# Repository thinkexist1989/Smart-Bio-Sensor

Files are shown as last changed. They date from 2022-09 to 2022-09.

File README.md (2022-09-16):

# Smart-Bio-Sensor

石墨烯生物传感器

- Hardware：硬件，包括了采集板、运放板、跳线版
- Firmware：固件，基于STM32CubeMX，采用HAL库
- Windows：Windows下的数据实时显示
- Android：Android端的数据实时采集

## Citation

```bibtex
@article{hao2021intelligent,
  title={An Intelligent Graphene-Based Biosensing Device for Cytokine Storm Syndrome Biomarkers Detection in Human Biofluids},
  author={Hao, Zhuang and Luo, Yang and Huang, Cong and Wang, Ziran and Song, Guoli and Pan, Yunlu and Zhao, Xuezeng and Liu, Shaoqin},
  journal={Small},
  volume={17},
  number={29},
  pages={2101508},
  year={2021},
  publisher={Wiley Online Library}
}
```

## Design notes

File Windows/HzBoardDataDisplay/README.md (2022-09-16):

# HzBoardDataDisplay V1.2

本程序是为了配合Hz Data Collection Board V5.0使用的，可以在PC端配置串口，自动采集数据并实时显示。基于Qt 和 Chart Director实现。目前版本为V1.2。

实现的功能如下：

+ **串口配置** 自动检测串口，设置串口波特率、校验位、停止位、数据位
+ **一键启动** 点击RUN按钮，自动和串口建立通讯，发送数据采集指令并接受返回数据
+ **实时显示** 三路电压实时显示，并可以选择单独显示每一路电压
+ **改变输出电压** 点击SET按钮，可以改变输出电压大小，单位mV
+ **改变界面大小** 为了适应郝壮这个大SB的Mackbook Pro的高分屏，添加了用于界面缩放的按钮，可以成比例缩放界面大小。

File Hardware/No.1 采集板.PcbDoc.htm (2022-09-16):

Reporting Options

# File in Newer Format

Date | : | 2018/4/19
Time | : | 10:31:07
Filename | : | D:\BaiduCloud\PHD PROJECTS\For HZ\HZ_Project5\No.1 꽃섞겼.PcbDoc

Version | Warning
Release 14 | CAUTION - The Differential Pairs Routing rule added support for control of the width. Be aware that these widths must be manually entered as Width rules in this version.
Release 15 | CAUTION - Support of separate solder masks for top & bottom of pads added.
Release 15.1 | CAUTION - Support Multi-line PCB Text added.
Release 16.0 | CAUTION - Pad/Via hole size tolerance value added.

This file was generated by a later version of the software

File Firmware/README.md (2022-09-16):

# DataCollectionBoard_v2_Code

+ 这份代码是配合自己开发的供电与电压采集板使用的。
+ 采集板采用stm32f407vet6+ads1274+dac8830实现DA输出供电与AD电压采集。
+ 基于Keil编写

### 采集板功能
采集板是用来给石墨烯生物采集芯片供电并采集其电流的。
+ 采集板需要实现10mV 稳定供电输出
+ 石墨烯生物采集芯片输出电流在10uA~20uA之间，需要利用运放芯片实现电流电压转换与放大，输出电压在0.5V左右
+ 需要实现高精度电压采集
+ 需要实时接受上位机指令并返回所需信息
+ 显示屏实时显示电压信息

### 采集板功能
+ MCU采用STM32F103C8T6芯片
+ 电压输出采用TI公司16位高精度DA芯片DAC8830（单路输出）
+ 电压采集采用TI公司24位高精度AD芯片ADS1274（四路输入）
+ 电流电压转换采用LT公司高精度运放LT1462。
+ 和上位机通讯采用串口通讯，芯片采用FTDI的FT232RL USB转串口芯片
+ 显示屏采用0.96寸LED显示屏

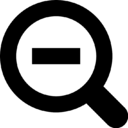
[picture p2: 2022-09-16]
Windows/HzBoardDataDisplay/zoomOut.png

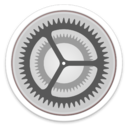
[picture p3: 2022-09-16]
Windows/HzBoardDataDisplay/Settings.png

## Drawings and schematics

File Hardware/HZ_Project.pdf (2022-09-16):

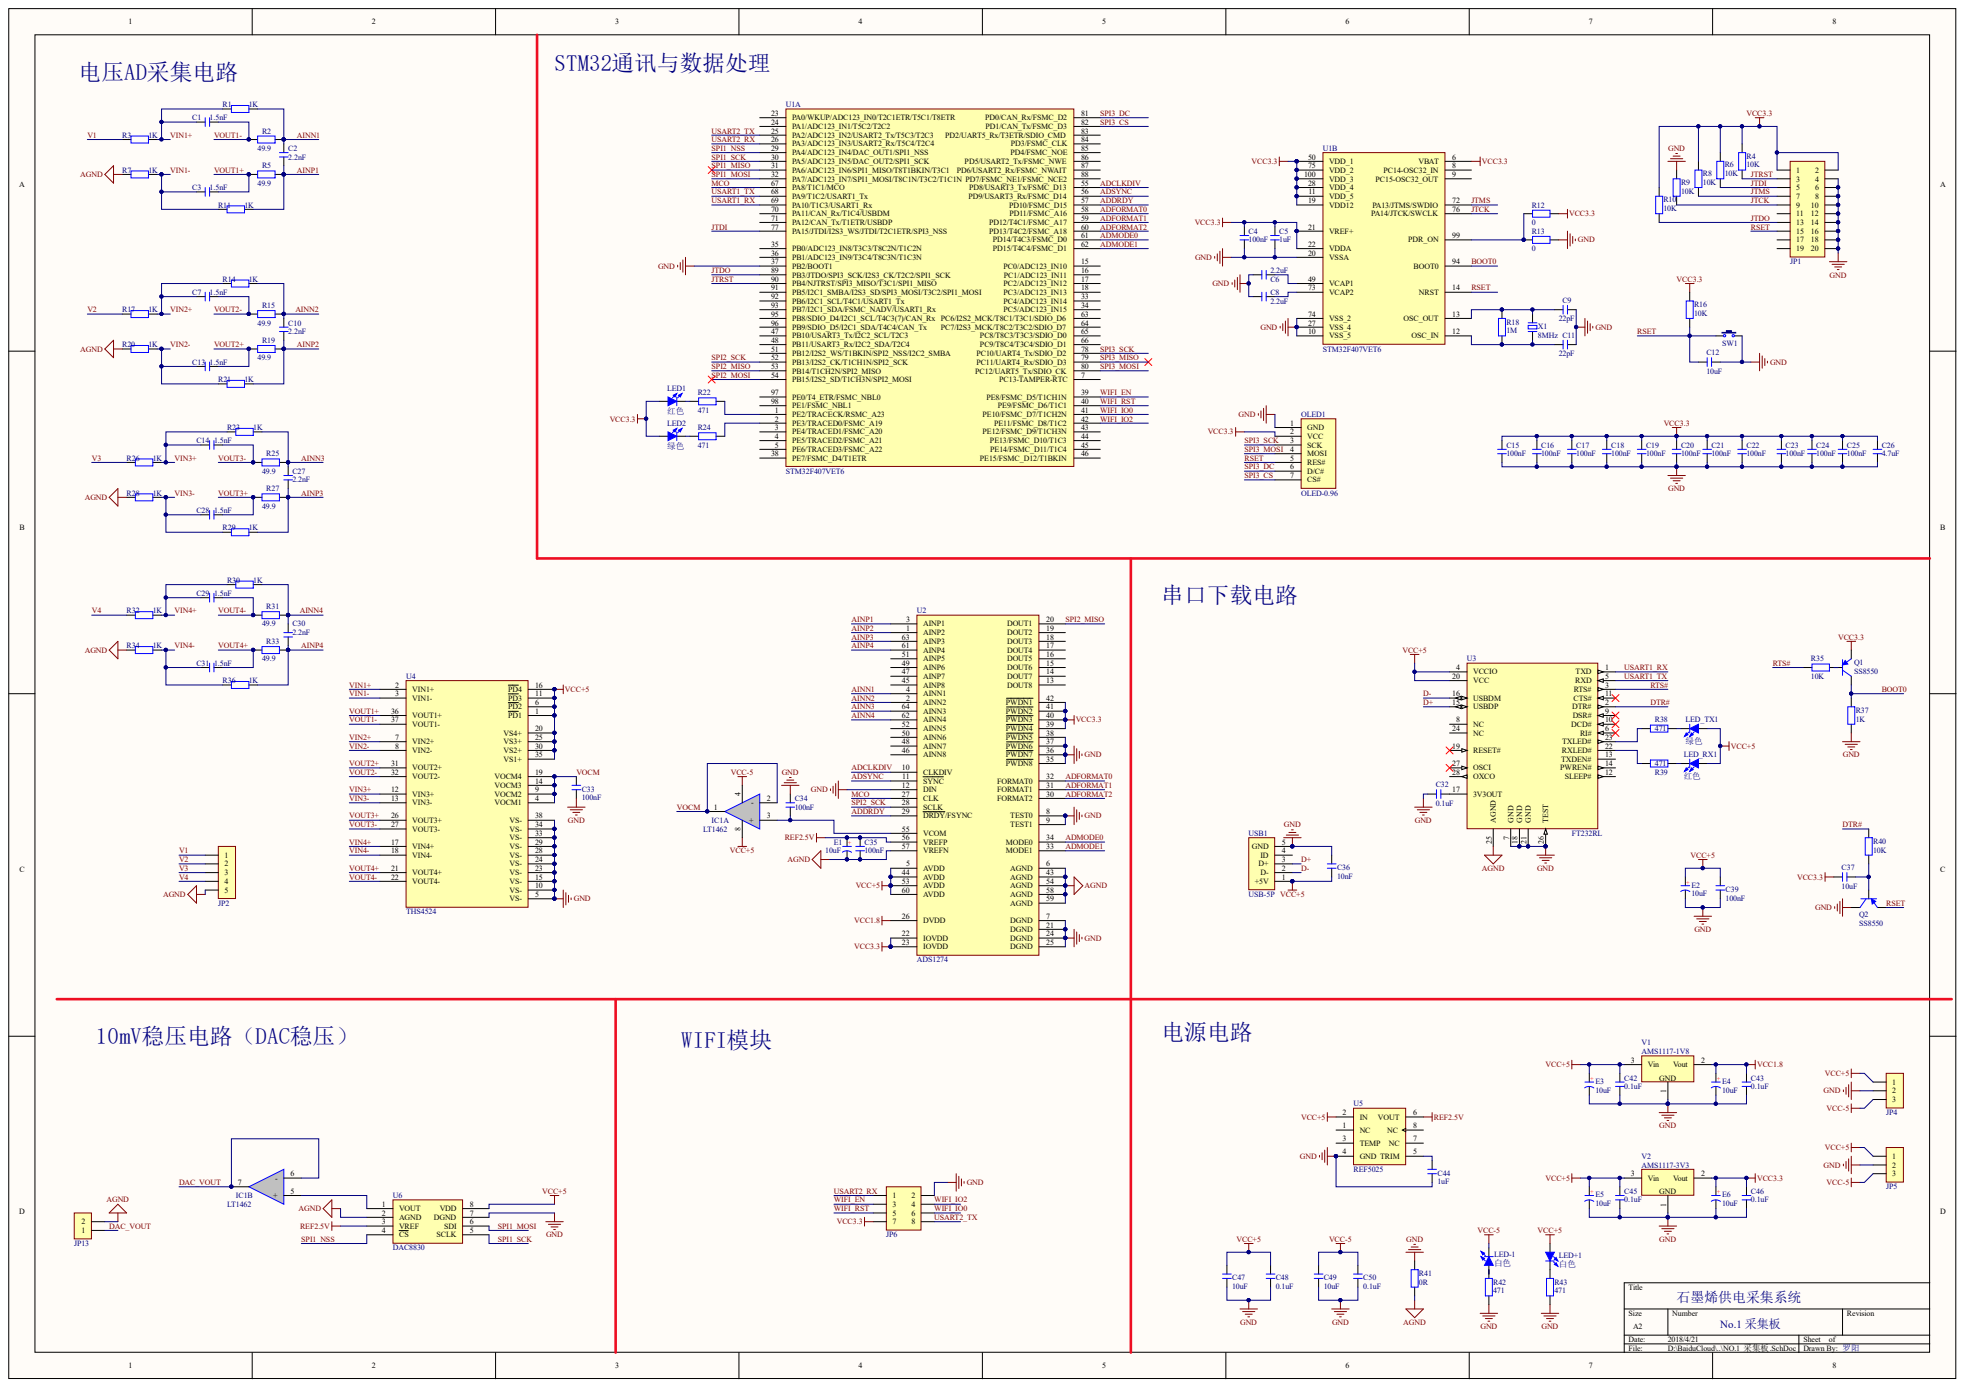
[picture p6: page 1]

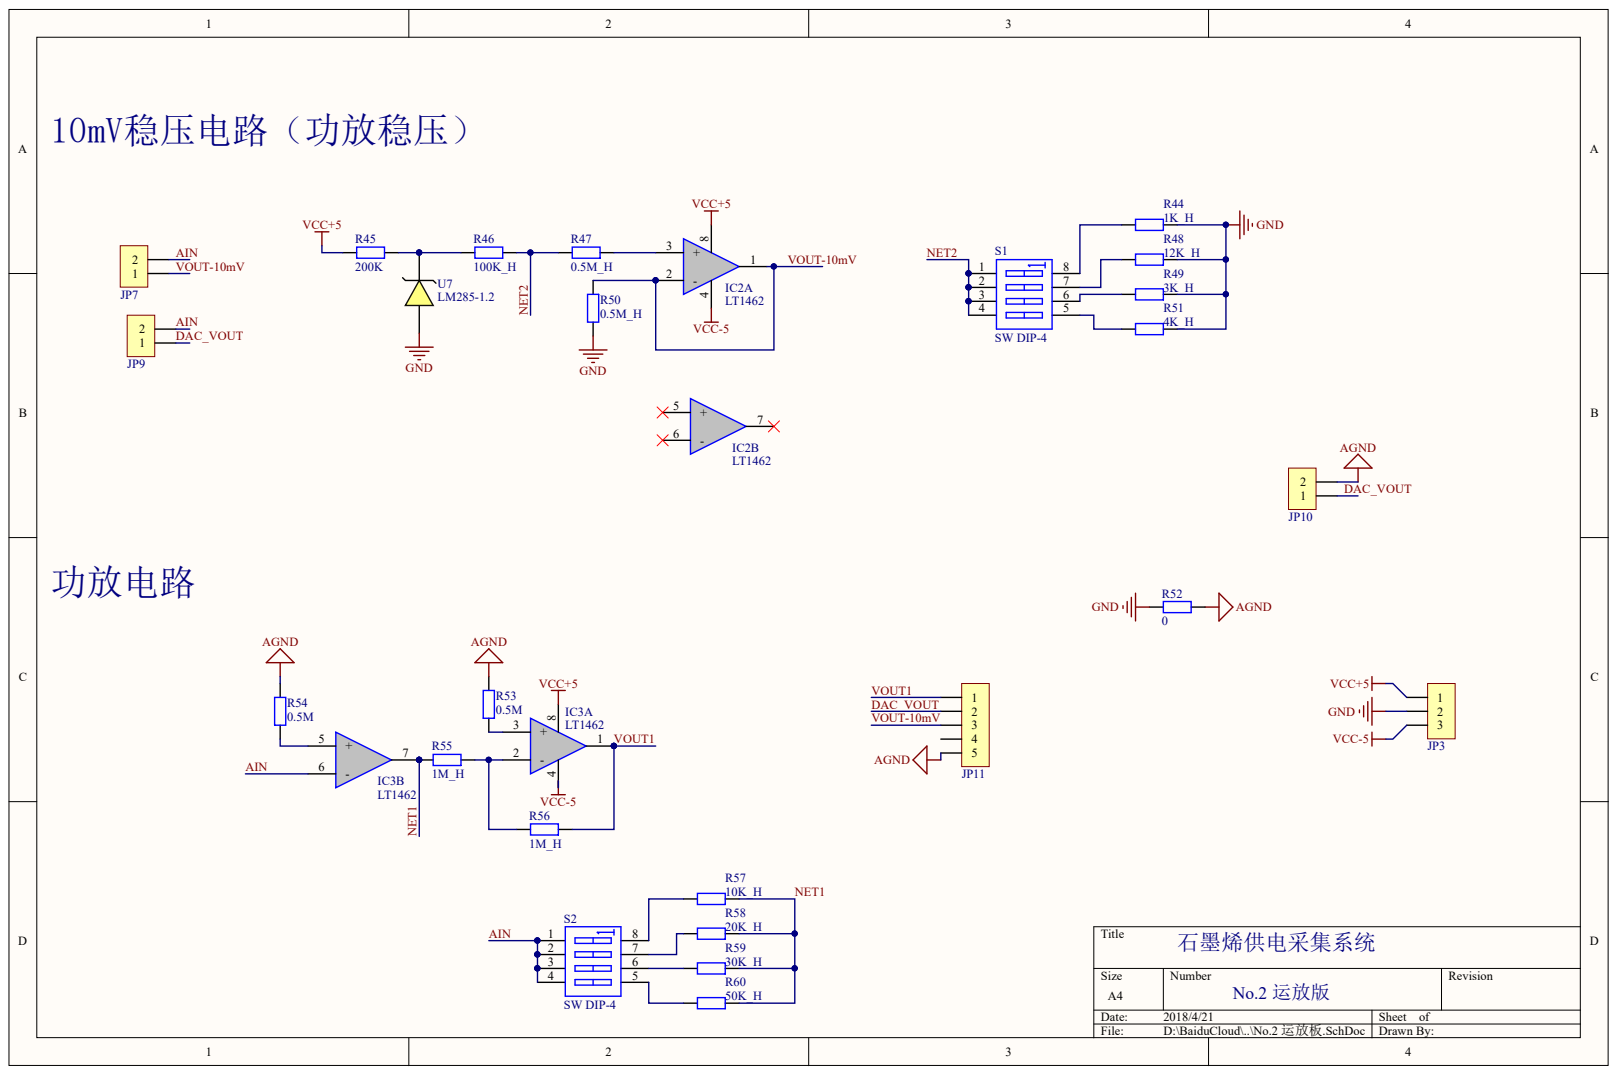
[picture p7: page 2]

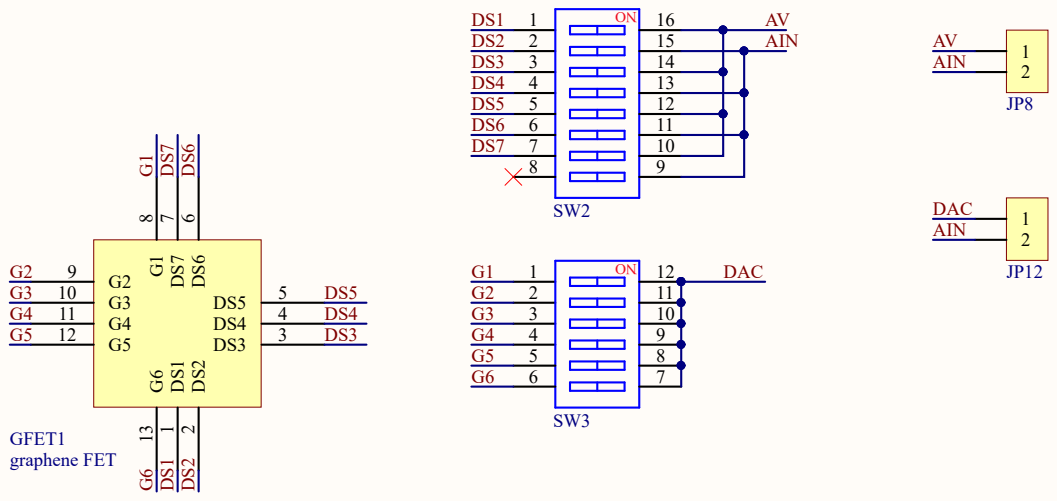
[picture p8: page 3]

12
1011

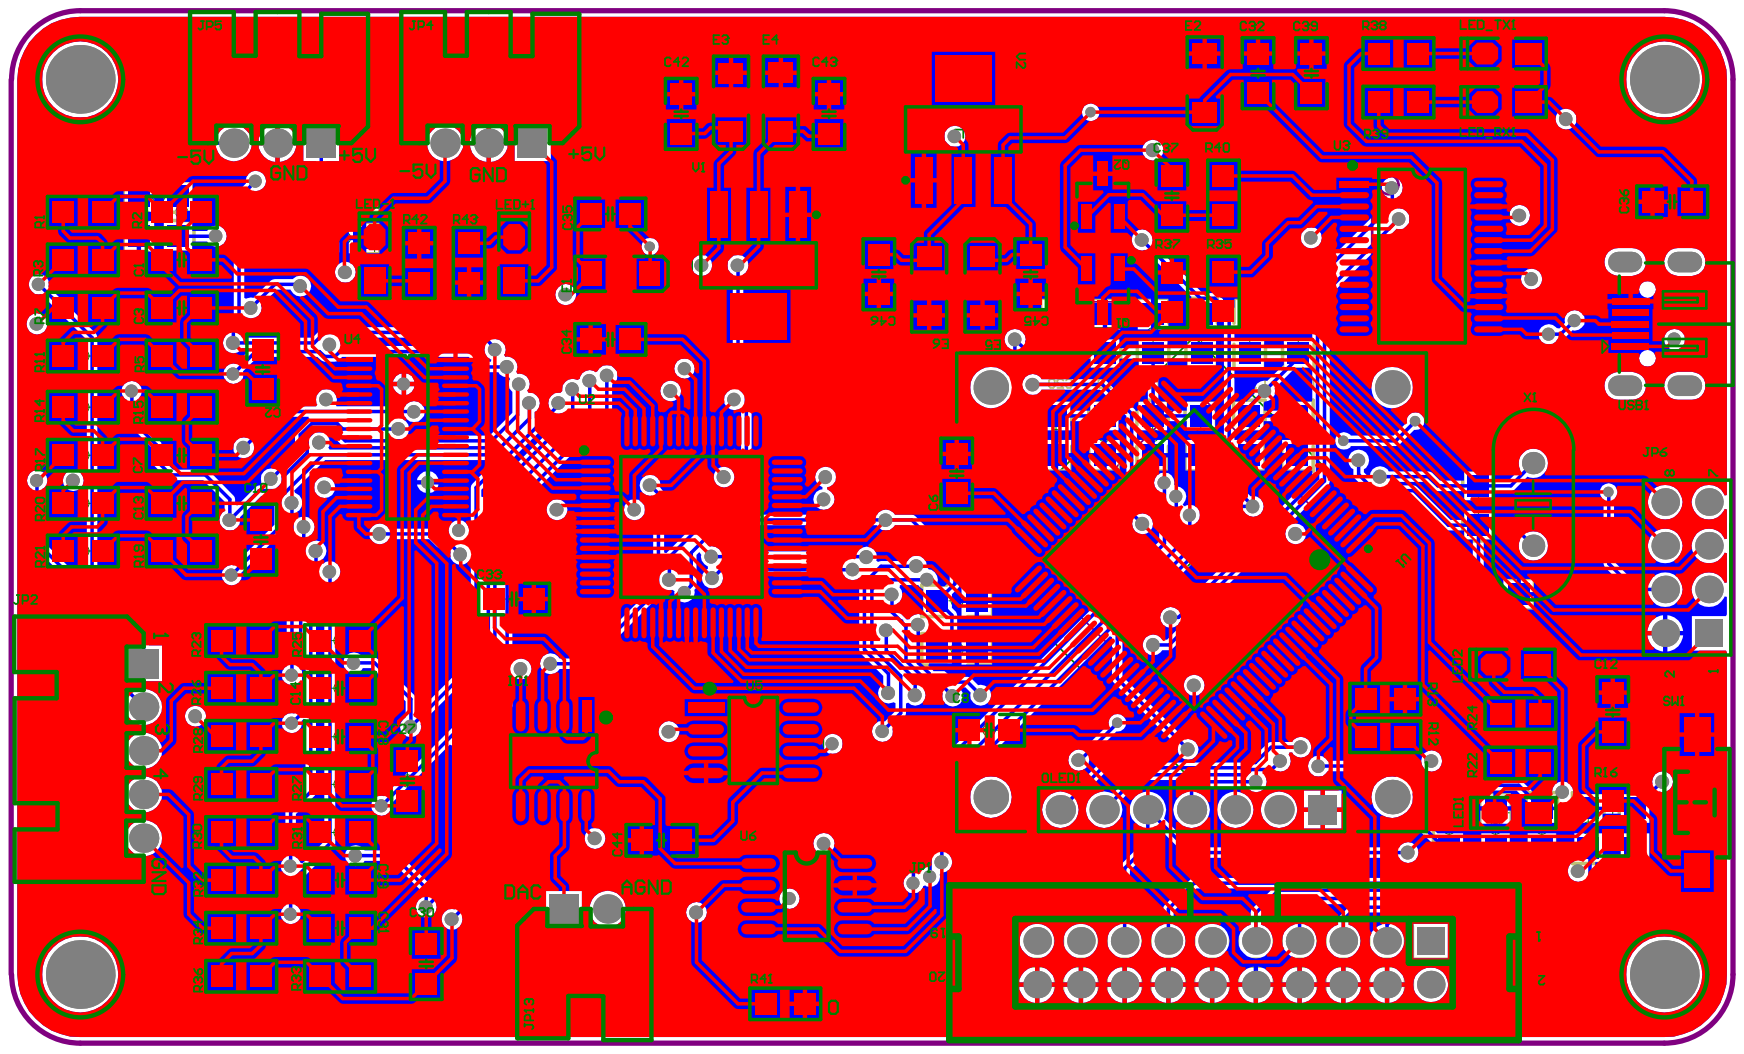
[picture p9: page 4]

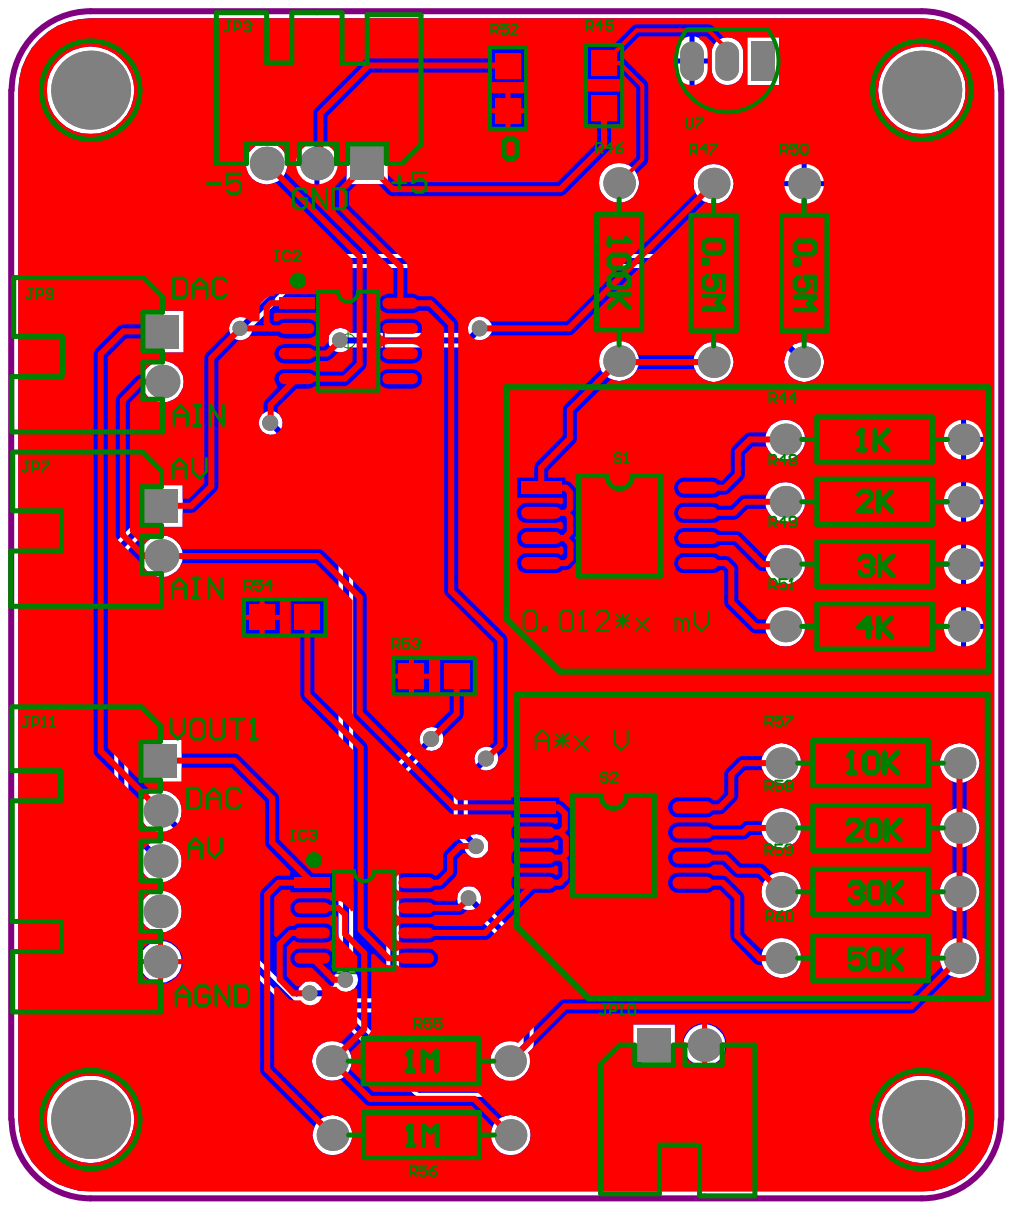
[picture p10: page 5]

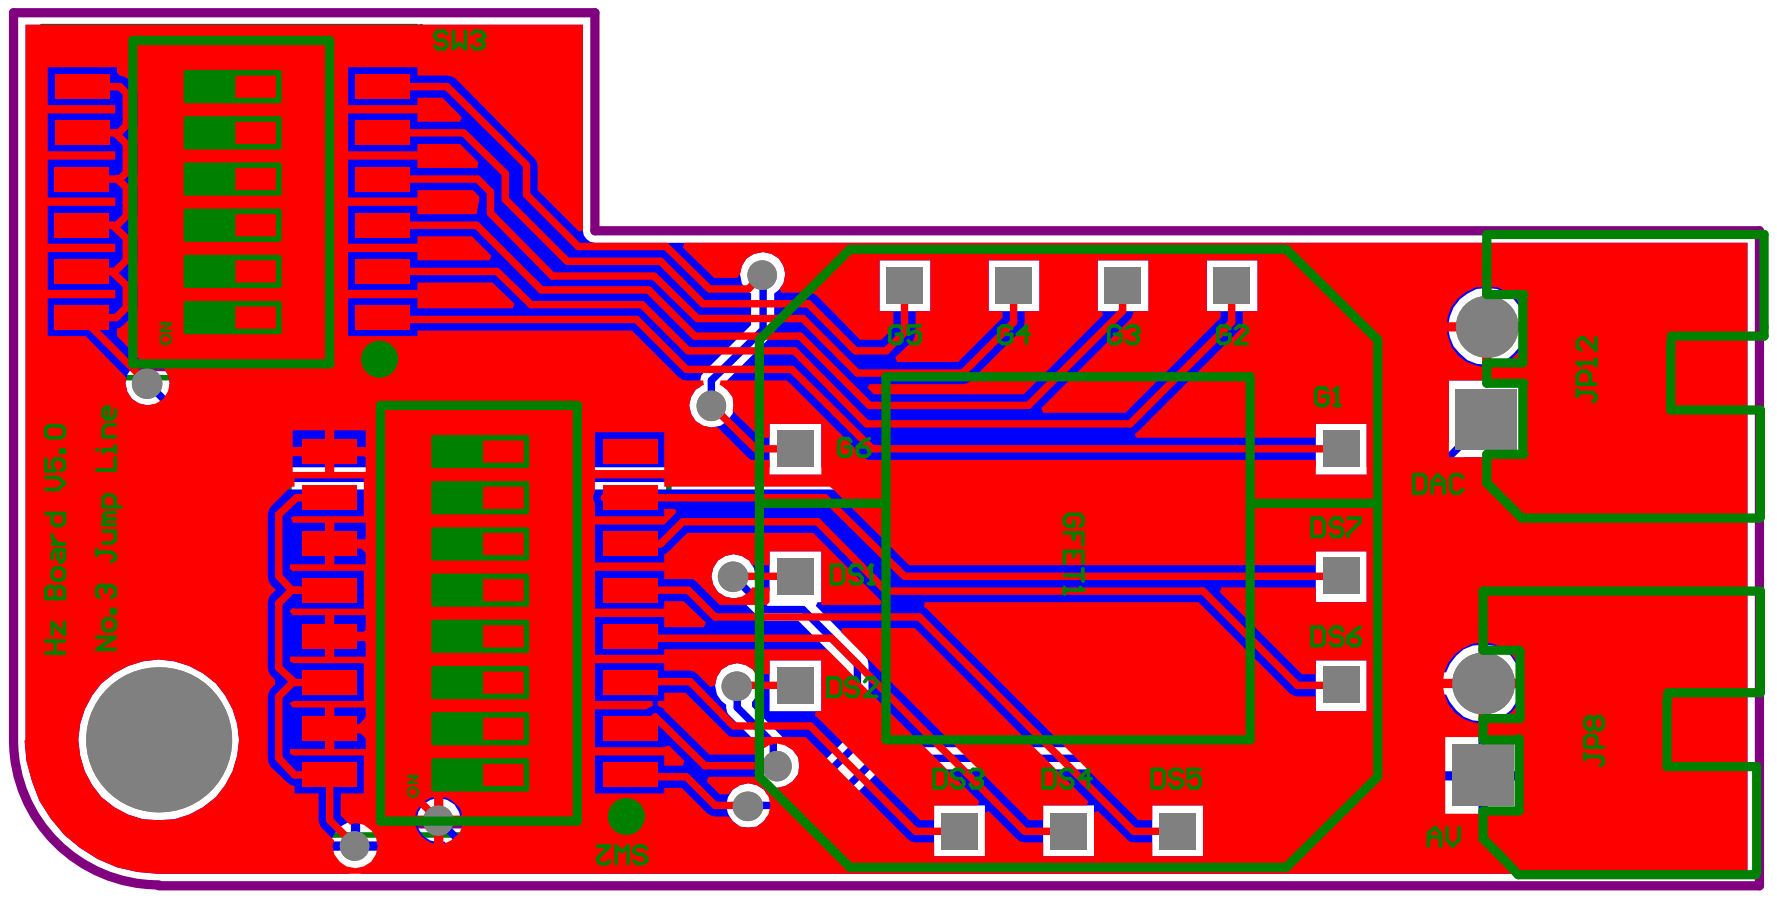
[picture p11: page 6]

Bill of Materials | 石墨烯供电采集系统
Source Data From: | HZ_Project.PrjPcb
Project: | | HZ_Project.PrjPcb
Variant: | | None
Creation Date: 2018/4/21 | 16:13:54
Print Date: | 43211 | 43211.67664
Footprint | Comment | LibRef | Designator | Description | Quantity
C 0805_M | 1.5nF | C | C1, C3, C7, C13, C14, C28, C29, C31 | 无极性贴片电容 | 8
C 0805_M | 2.2nF | C | C2, C10, C27, C30 | 无极性贴片电容 | 4
C 0805_M | 100nF | C | C4, C15, C16, C17, C18, C19, C20, C21,
| | | C22, C23, C24, C25, C33, C34, C35, C39 | 无极性贴片电容 | 16
C 0805_M | 1uF | C | C5, C44 | 无极性贴片电容 | 2
C 0805_M | 2.2uF | C | C6, C8 | 无极性贴片电容 | 2
C 0805_M | 22pF | C | C9, C11 | 无极性贴片电容 | 2
C 0805_M | 10uF | C | C12, C37, C47, C49 | 无极性贴片电容 | 4
C 0805_M | 4.7uF | C | C26 | 无极性贴片电容 | 1
C 0805_M | 0.1uF | C | C32, C42, C43, C45, C46, C48, C50 | 无极性贴片电容 | 7
C 0805_M | 10nF | C | C36 | 无极性贴片电容 | 1
CD A(3216) | 10uF | C-CD, C-CM, C-
| | CD, C-CD, C-
| | CD, C-CD | E1, E2, E3, E4, E5, E6 | 贴片钽电容, 贴片电解电容, 贴片钽电容, 贴

## 片钽电容, 贴片钽电容, 贴片钽电容

| | | | | 6

## graphene FET

| graphene FET | graphene FET | GFET1 | | 1
SOP8_N | LT1462 | LT1678 | IC1, IC2, IC3 | 双运放 | 3
IDC2.54-LI- 2x10P | Header 2X10 | Header 10X2 | JP1 | 10*2P接插件 | 1
XH2.54-WI- 5P | HDR-1X5 | Header 5 | JP2, JP11 | 5P接插件 | 2
XH2.54-WI- 3P | HDR-1X3 | Header 3 | JP3, JP4, JP5 | 3P接插件 | 3
HDR2.54-LI- 2x4P | Header 4X2 | Header 4X2 | JP6 | 4*2P接插件 | 1
XH2.54-WI- 2P | HDR-1X2 | Header 2 | JP7, JP8, JP9, JP10, JP12, JP13 | 2P接插件 | 6
LED 0805R | 红色 | LED-SMD | LED1, LED_RX1 | 贴片LED | 2
LED 0805G | 绿色 | LED-SMD | LED2, LED_TX1 | 贴片LED | 2
LED 0805W | 白色 | LED-SMD | LED+1, LED-1 | 贴片LED | 2
OLED | OLED-0.96 | OLED-0.96 | OLED1 | | 1
SOT23-3M | SS8550 | 8550-SMD | Q1, Q2 | 高频放大-PNP型 | 2
R 0805_M | 1K | R | R1, R3, R7, R11, R14, R17, R20, R21,
| | | R23, R26, R28, R29, R30, R32, R34, R36,
| | | R37 | 贴片电阻 | 17
R 0805_M | 49.9 | R | R2, R5, R15, R19, R25, R27, R31, R33 | 贴片电阻 | 8
R 0805_M | 10K | R | R4, R6, R8, R9, R10, R16, R35, R40 | 贴片电阻 | 8
R 0805_M | 0 | R | R12, R13, R52 | 贴片电阻 | 3
R 0805_M | 1M | R | R18 | 贴片电阻 | 1
R 0805_M | 471 | R | R22, R24, R38, R39, R42, R43 | 贴片电阻 | 6
R 0805_M | 0R | R | R41 | 贴片电阻 | 1
RS 1/4W | 1K_H | R | R44 | 贴片电阻 | 1
R 0805_M | 200K | R | R45 | 贴片电阻 | 1
RS 1/4W | 100K_H | R | R46 | 贴片电阻 | 1
RS 1/4W | 0.5M_H | R | R47, R50 | 贴片电阻 | 2
RS 1/4W | 12K_H | R | R48 | 贴片电阻 | 1
RS 1/4W | 3K_H | R | R49 | 贴片电阻 | 1
RS 1/4W | 4K_H | R | R51 | 贴片电阻 | 1
R 0805_M | 0.5M | R | R53, R54 | 贴片电阻 | 2
RS 1/4W | 1M_H | R | R55, R56 | 贴片电阻 | 2
RS 1/4W | 10K_H | R | R57 | 贴片电阻 | 1
RS 1/4W | 20K_H | R | R58 | 贴片电阻 | 1
RS 1/4W | 30K_H | R | R59 | 贴片电阻 | 1
RS 1/4W | 50K_H | R | R60 | 贴片电阻 | 1
SO-8M | SW DIP-4 | SW DIP-4 | S1, S2 | DIP Switch, 4 Position, SPST | 2
TSW SMD- 3*6*2.5 | 3x6x5 | TSW 3x6 | SW1 | 3x6轻触开关 | 1
CSW1.27 SMD-8P | CSW-8P | CSW-8P | SW2 | 8路编码开关 | 1
CSW1.27 SMD-6P | CSW-6P | CSW-6P | SW3 | 6路编码开关 | 1
LQFP-100_M | STM32F407VET
| 6 | STM32F407V | U1 | STM32单片机100引脚 | 1
TQFP64- 10*10 | ADS1274 | ADS1274/ADS1
| | 278 | U2 | | 1
SSOP28_N | FT232RL | FT232RL | U3 | USB转串口 | 1
TSSOP-38 - duplicate | THS4524 | THS4524 | U4 | | 1
SOP8_M | REF5025 | REF5040 | U5 | 高精度电压基准 | 1
SOP8 | DAC8830 | DAC8830 | U6 | | 1
TO92A | LM285-1.2 | LM285-1.2 | U7 | | 1
USB- MICRO_D | USB-5P | USB-5P | USB1 | 微型USB母座 | 1
SOT223_M | AMS1117-1V8 | AMS1117 | V1 | 三端稳压芯片 | 1
SOT223_M | AMS1117-3V3 | AMS1117 | V2 | 三端稳压芯片 | 1
OSC HC-49S | 8MHz | XTAL-2P | X1 | 2脚无源脚晶振 | 1
| | | | | 155
Approved | | Notes

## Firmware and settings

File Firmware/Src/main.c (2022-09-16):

/**
  ******************************************************************************
  * File Name          : main.c
  * Description        : Main program body
  ******************************************************************************
  ** This notice applies to any and all portions of this file
  * that are not between comment pairs USER CODE BEGIN and
  * USER CODE END. Other portions of this file, whether 
  * inserted by the user or by software development tools
  * are owned by their respective copyright owners.
  *
  * COPYRIGHT(c) 2018 STMicroelectronics
  *
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
  ******************************************************************************
  */

/* Includes ------------------------------------------------------------------*/
#include "main.h"
#include "stm32f4xx_hal.h"
#include "crc.h"
#include "dma.h"
#include "spi.h"
#include "tim.h"
#include "usart.h"
#include "gpio.h"

/* USER CODE BEGIN Includes */

/***********有几点注意事项***********
*1. ADS1274 SPI通信必须配置为全双工master，要不然数据就不对
*2. DMA通讯的sendbuf一定要全局变量或静态变量，因为是放到内存里慢慢发，临时变量数就不对了
*************************************/
#include "oled.h"
#include "ads1274.h"
#include "dac8830.h"

#include <string.h>
#include <math.h>

/* USER CODE END Includes */


/* USER CODE BEGIN PV */

/* USER CODE END PV */

void SystemClock_Config(void);

/* USER CODE BEGIN PFP */
void InitWIFI(void)
{
			uint8_t tempbuf[256]={'\0'};
			HAL_Delay(5000);
			sprintf((char*)tempbuf,"AT+CIPSTART=\"TCP\",\"192.168.1.100\",8080\r\n");		 //连接热TCPIP服务器
			HAL_UART_Transmit(&huart2,tempbuf,100,0xFFFF);
			
			HAL_Delay(1000);
			memcpy(tempbuf,'\0',256);
			sprintf((char*)tempbuf,"AT+CIPMODE=1\r\n");		 //1透传模式
			HAL_UART_Transmit(&huart2,tempbuf,100,0xFFFF);
			
			HAL_Delay(1000);
			memcpy(tempbuf,'\0',256);
			sprintf((char*)tempbuf,"AT+CIPSEND\r\n");		 //连接热TCPIP服务器
			HAL_UART_Transmit(&huart2,tempbuf,100,0xFFFF);
			HAL_Delay(1000);
			
}
/* USER CODE END PFP */

/* USER CODE BEGIN 0 */
uint8_t bDisplay = 0;

/* USER CODE END 0 */

int main(void)
{

  /* USER CODE BEGIN 1 */
	uint8_t disp[256]={0};
  /* USER CODE END 1 */

  /* MCU Configuration----------------------------------------------------------*/

  /* Reset of all peripherals, Initializes the Flash interface and the Systick. */
  HAL_Init();

  /* Configure the system clock */
  SystemClock_Config();

  /* Initialize all configured peripherals */
  MX_GPIO_Init();
  MX_DMA_Init();
  MX_CRC_Init();
  MX_SPI1_Init();
  MX_SPI2_Init();
  MX_SPI3_Init();
  MX_USART1_UART_Init();
  MX_USART2_UART_Init();
  MX_TIM3_Init();

  /* USER CODE BEGIN 2 */
	OLED_ShowString(0,3,(uint8_t*)"Initializing");   //装逼用
	OLED_Init();
	OLED_Clear();
	//ADS1274_Init();
	HAL_UART_Receive_IT(&huart1, (uint8_t *)(&RxBuf[uart.iRxPtr]), 1);
	HAL_TIM_Base_Start_IT(&htim3);
	
	
	//InitWIFI();
	OLED_Clear();
	OLED_ShowString(0,3,(uint8_t*)"Complete!!!"); //装逼用
	HAL_Delay(1000);
	
	iDacMv = 10;
	DAC_SetVout(iDacMv);
	
	
	uart.bSended2 = TRUE;
	uart.bSended1 = TRUE;

	
	
  /* USER CODE END 2 */

  /* Infinite loop */
  /* USER CODE BEGIN WHILE */
  while (1)
  {
  /* USER CODE END WHILE */

  /* USER CODE BEGIN 3 */
		if(bDisplay){
			bDisplay = 0;
			
			OLED_ShowString(0,0,(uint8_t*)"GFET Nanosensor");
			sprintf((char* )disp,"Vg: %-7.3lf mV",vout[1]*1000);
			//sprintf((char* )disp,"VAL: %d",123);
		
			OLED_ShowString(0,3,disp); 
		  
			double val = 0.17712*pow((0.999884*v0-vout[0])/(vout[0]-1.064789*v0),0.69558);
			sprintf((char* )disp,"CI: %-7.5lf nM",val);
			OLED_ShowString(0,6,disp);
		}

		if(bAdsDataReady){
			bAdsDataReady = 0;
			ADS1274_ProcessData();
		}
		
		if(bUartNewData == TRUE){
			bUartNewData = FALSE;
			dataFrame_OK(&uart, RxBuf);
		}		
  }
	
	//HAL_Delay(100);
  /* USER CODE END 3 */

}

/** System Clock Configuration
*/
void SystemClock_Config(void)
{

  RCC_OscInitTypeDef RCC_OscInitStruct;
  RCC_ClkInitTypeDef RCC_ClkInitStruct;

    /**Configure the main internal regulator output voltage 
    */
  __HAL_RCC_PWR_CLK_ENABLE();

  __HAL_PWR_VOLTAGESCALING_CONFIG(PWR_REGULATOR_VOLTAGE_SCALE1);

    /**Initializes the CPU, AHB and APB busses clocks 
    */
  RCC_OscInitStruct.OscillatorType = RCC_OSCILLATORTYPE_HSE;
  RCC_OscInitStruct.HSEState = RCC_HSE_ON;
  RCC_OscInitStruct.PLL.PLLState = RCC_PLL_ON;
  RCC_OscInitStruct.PLL.PLLSource = RCC_PLLSOURCE_HSE;
  RCC_OscInitStruct.PLL.PLLM = 8;
  RCC_OscInitStruct.PLL.PLLN = 336;
  RCC_OscInitStruct.PLL.PLLP = RCC_PLLP_DIV2;
  RCC_OscInitStruct.PLL.PLLQ = 4;
  if (HAL_RCC_OscConfig(&RCC_OscInitStruct) != HAL_OK)
  {
    _Error_Handler(__FILE__, __LINE__);
  }

    /**Initializes the CPU, AHB and APB busses clocks 
    */
  RCC_ClkInitStruct.ClockType = RCC_CLOCKTYPE_HCLK|RCC_CLOCKTYPE_SYSCLK
                              |RCC_CLOCKTYPE_PCLK1|RCC_CLOCKTYPE_PCLK2;
  RCC_ClkInitStruct.SYSCLKSource = RCC_SYSCLKSOURCE_PLLCLK;
  RCC_ClkInitStruct.AHBCLKDivider = RCC_SYSCLK_DIV1;
  RCC_ClkInitStruct.APB1CLKDivider = RCC_HCLK_DIV4;
  RCC_ClkInitStruct.APB2CLKDivider = RCC_HCLK_DIV2;

  if (HAL_RCC_ClockConfig(&RCC_ClkInitStruct, FLASH_LATENCY_5) != HAL_OK)
  {
    _Error_Handler(__FILE__, __LINE__);
  }

  HAL_RCC_MCOConfig(RCC_MCO1, RCC_MCO1SOURCE_HSE, RCC_MCODIV_1);

    /**Configure the Systick interrupt time 
    */
  HAL_SYSTICK_Config(HAL_RCC_GetHCLKFreq()/1000);

    /**Configure the Systick 
    */
  HAL_SYSTICK_CLKSourceConfig(SYSTICK_CLKSOURCE_HCLK);

  /* SysTick_IRQn interrupt configuration */
  HAL_NVIC_SetPriority(SysTick_IRQn, 0, 0);
}

/* USER CODE BEGIN 4 */
void HAL_TIM_PeriodElapsedCallback(TIM_HandleTypeDef *htim)
{

	if (htim->Instance == htim3.Instance){
		//bDisplay = 1;
		
		static uint8_t iii = 0;
		if(iii++ >= 10){
			bDisplay = 1;
			HAL_GPIO_TogglePin(LED1_GPIO_Port,LED1_Pin);
			HAL_GPIO_TogglePin(LED2_GPIO_Port,LED2_Pin);
			iii=0;
			
			memcpy(TxBuf2,'\0',256);
			sprintf((char*)TxBuf2,"Vout1: %f, Vout2: %f, Vout3: %f, Vout4: %f\n", vout[0],vout[1],vout[2],vout[3]);
			HAL_UART_Transmit_DMA(&huart2,TxBuf2,strlen(TxBuf2));
			
			//HAL_UART_Transmit(&huart2,tempbuf,strlen(tempbuf),0xFFFF);
		}

	}

}

/* USER CODE END 4 */
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


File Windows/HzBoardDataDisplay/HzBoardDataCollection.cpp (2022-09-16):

#include <QApplication>
#include <QButtonGroup>
#include <QIcon>
#include <QPushButton>
#include <QComboBox>
#include <QCheckBox>
#include "HzBoardDataCollection.h"
#include "chartdir.h"
#include <math.h>
#include <stdio.h>

#include <QDebug>
#include <QScreen>
#include <QStyleFactory>


#define AVETIMES  10
#define INFODISPLAY "Hz Board Data Collection v1.2"

int cnt = 0;
float TIMES = 0;
int main(int argc, char *argv[])
{
   // QApplication::setAttribute(Qt::AA_EnableHighDpiScaling); //高分屏支持
    QApplication app(argc, argv);
    app.setStyleSheet("* {font-family:arial;font-size:11px}");
    DataCollection demo;
    demo.show();
    return app.exec();
}


static const int DataInterval = 200;

DataCollection::DataCollection(QWidget *parent) :
    QDialog(parent),m_RcvPtr(0),m_GetPtr(0),bDataA(false),bDataB(false),bDataC(false)
{
    //
    // Set up the GUI
    //
    QScreen *screen=QGuiApplication::primaryScreen ();
    qDebug()<<screen->availableGeometry();
    QRect mm=screen->availableGeometry() ;
    qDebug()<<mm.width ()<<mm.height ();//主屏幕分辨率的大小
    TIMES = mm.width()/1920.0;

    //setFixedSize(740, 285);
    setFixedSize(740*TIMES, 455*TIMES);
    setWindowTitle(INFODISPLAY);
    setWindowIcon(QIcon(":/vout.png"));

    // The frame on the left side
    frame = new QFrame(this);
    frame->setGeometry(4*TIMES, 4*TIMES, 120*TIMES, 445*TIMES);
    frame->setFrameShape(QFrame::StyledPanel);

    // Run push button
    runPB = new QPushButton(QIcon(":/play.png"), "Run", frame);
    runPB->setGeometry(4*TIMES, 8*TIMES, 112*TIMES, 28*TIMES);
    runPB->setStyleSheet("QPushButton { text-align:left; padding:5px}");
    runPB->setCheckable(true);

    // Freeze push button
    freezePB = new QPushButton(QIcon(":/pause.png"), "Pause", frame);
    freezePB->setGeometry(4*TIMES, 36*TIMES, 112*TIMES, 28*TIMES);
    freezePB->setStyleSheet("QPushButton { text-align:left; padding:5px}");
    freezePB->setCheckable(true);

    // The Run/Freeze buttons form a button group
    runFreezeControl = new QButtonGroup(frame);
    runFreezeControl->addButton(runPB, 1);
    runFreezeControl->addButton(freezePB, 0);
    connect(runFreezeControl, SIGNAL(buttonPressed(int)), SLOT(onRunFreezeChanged(int)));

    /**************** 串口号选择ComboBox******************/
    serialLabel = new QLabel("Serial Port", frame);
    serialLabel->setGeometry(6*TIMES, 80*TIMES, 108*TIMES, 16*TIMES);
    //(new QLabel("Serial Port", frame))->setGeometry(6*TIMES, 80*TIMES, 108*TIMES, 16*TIMES);
    serialPort = new QComboBox(frame);
    serialPort->setGeometry(6*TIMES, 96*TIMES, 108*TIMES, 21*TIMES);

    foreach(const QSerialPortInfo &qspinfo, QSerialPortInfo::availablePorts()){
               serialPort->addItem(qspinfo.portName());
               //ui->textEdit->append("portname   " + qspinfo.portName());
              // ui->textEdit->append("description:   " + qspinfo.description());
              // ui->textEdit->append("manufacture    "+ qspinfo.manufacturer());
              // ui->textEdit->append("serialnumber   "+ qspinfo.serialNumber());
              // ui->textEdit->append("systemlocation "+qspinfo.serialNumber());
    }
    serialPort->setCurrentIndex(0);
    m_PortName = serialPort->currentText();

    memset(m_RcvBuf,0,256);
    connect(serialPort, SIGNAL(currentIndexChanged(QString)),SLOT(onSerialPortChanged(QString)));

    /*************** 波特率选择ComboBox******************/
    baudRateLabel = new QLabel("Baud Rate", frame);
    baudRateLabel->setGeometry(6*TIMES, 120*TIMES, 108*TIMES, 16*TIMES);
    //(new QLabel("Baud Rate", frame))->setGeometry(6*TIMES, 120*TIMES, 108*TIMES, 16*TIMES);
    baudRate = new QComboBox(frame);
    baudRate->setGeometry(6*TIMES, 136*TIMES, 108*TIMES, 21*TIMES);
    baudRate->addItems(QStringList()<<"9600"<<"19200"<<"38400"<<"115200");
    baudRate->setCurrentIndex(3);
    m_BaudRate = QSerialPort::Baud115200;
    connect(baudRate, SIGNAL(currentIndexChanged(QString)),SLOT(onBaudRateChanged(QString)));

    /*************** 校验位选择ComboBox******************/
    parityBitsLabel = new QLabel("Parity Bits", frame);
    parityBitsLabel->setGeometry(6*TIMES, 160*TIMES, 108*TIMES, 16*TIMES);
    //(new QLabel("Parity Bits", frame))->setGeometry(6*TIMES, 160*TIMES, 108*TIMES, 16*TIMES);
    parityBits = new QComboBox(frame);
    parityBits->setGeometry(6*TIMES, 176*TIMES, 108*TIMES, 21*TIMES);
    parityBits->addItems(QStringList()<<"No Parity"<<"Odd Parity"<<"Even Parity");
    parityBits->setCurrentIndex(0);
    m_ParityBits = QSerialPort::NoParity;

    connect(parityBits, SIGNAL(currentIndexChanged(int)),SLOT(onParityBitsChanged(int)));

    /*************** 数据位选择ComboBox******************/
    dataBitsLabel = new QLabel("Data Bits", frame);
    dataBitsLabel->setGeometry(6*TIMES, 200*TIMES, 108*TIMES, 16*TIMES);
    //(new QLabel("Data Bits", frame))->setGeometry(6*TIMES, 200*TIMES, 108*TIMES, 16*TIMES);
    dataBits = new QComboBox(frame);
    dataBits->setGeometry(6*TIMES, 216*TIMES, 108*TIMES, 21*TIMES);
    dataBits->addItems(QStringList()<<"4 bits"<<"5 bits"<<"6 bits"<<"7 bits"<<"8 bits");
    dataBits->setCurrentIndex(4);
    m_DataBits = QSerialPort::Data8;

    connect(dataBits, SIGNAL(currentIndexChanged(int)),SLOT(onDataBitsChanged(int)));

    /*************** 停止位选择ComboBox******************/
    stopBitsLabel = new QLabel("Stop Bits", frame);
    stopBitsLabel->setGeometry(6*TIMES, 240*TIMES, 108*TIMES, 16*TIMES);
    //(new QLabel("Stop Bits", frame))->setGeometry(6*TIMES, 240*TIMES, 108*TIMES, 16*TIMES);
    stopBits = new QComboBox(frame);
    stopBits->setGeometry(6*TIMES, 256*TIMES, 108*TIMES, 21*TIMES);
    stopBits->addItems(QStringList()<<"1 bit"<<"1.5 bits"<<"2 bits");
    stopBits->setCurrentIndex(0);
    m_StopBits = QSerialPort::OneStop;

    connect(stopBits, SIGNAL(currentIndexChanged(int)),SLOT(onStopBitsChanged(int)));


//    slider = new QSlider(Qt::Horizontal,frame);
//    slider->setStyle(QStyleFactory::create("Fusion"));
//    slider->setGeometry(6*TIMES, 280*TIMES, 108*TIMES, 16*TIMES);
//    slider->setValue(10);

//    slider->setMaximum(40);
//    slider->setMinimum(10);
//    slider->
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

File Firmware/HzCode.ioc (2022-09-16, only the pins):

Mcu.UserName=STM32F407VETx
PA10.Signal=USART1_RX
PA13.Signal=SYS_JTMS-SWDIO
PA14.Signal=SYS_JTCK-SWCLK
PA15.Signal=SYS_JTDI
PA2.Signal=USART2_TX
PA3.Signal=USART2_RX
PA4.GPIO_Label=SPI1_CS
PA4.Signal=GPIO_Output
PA5.Signal=SPI1_SCK
PA6.Signal=SPI1_MISO
PA7.Signal=SPI1_MOSI
PA8.Signal=RCC_MCO_1
PA9.Signal=USART1_TX
PB13.Signal=SPI2_SCK
PB14.Signal=SPI2_MISO
PB3.Signal=SYS_JTDO-SWO
PB4.Signal=SYS_JTRST
PC10.Signal=SPI3_SCK
PC11.Signal=SPI3_MISO
PC12.Signal=SPI3_MOSI
PC3.Signal=SPI2_MOSI
PD0.GPIO_Label=SPI3_DC
PD0.Signal=GPIO_Output
PD1.GPIO_Label=SPI3_CS
PD1.Signal=GPIO_Output
PD10.GPIO_Label=ADDRDY
PD10.Signal=GPXTI10
PD11.GPIO_Label=ADFORMAT0
PD11.Signal=GPIO_Output
PD12.GPIO_Label=ADFORMAT1
PD12.Signal=GPIO_Output
PD13.GPIO_Label=ADFORMAT2
PD13.Signal=GPIO_Output
PD14.GPIO_Label=ADMODE0
PD14.Signal=GPIO_Output
PD15.GPIO_Label=ADMODE1
PD15.Signal=GPIO_Output
PD8.GPIO_Label=ADCLKDIV
PD8.Signal=GPIO_Output
PD9.GPIO_Label=ADSYNC
PD9.Signal=GPIO_Output
PE10.GPIO_Label=WIFI_IO0
PE10.Signal=GPIO_Output
PE11.GPIO_Label=WIFI_IO2
PE11.Signal=GPIO_Output
PE2.GPIO_Label=LED1
PE2.Signal=GPIO_Output
PE3.GPIO_Label=LED2
PE3.Signal=GPIO_Output
PE8.GPIO_Label=WIFI_EN
PE8.Signal=GPIO_Output
PE9.GPIO_Label=WIFI_RST
PE9.Signal=GPIO_Output
PH0-OSC_IN.Signal=RCC_OSC_IN
PH1-OSC_OUT.Signal=RCC_OSC_OUT

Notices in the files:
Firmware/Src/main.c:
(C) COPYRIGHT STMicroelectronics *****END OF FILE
